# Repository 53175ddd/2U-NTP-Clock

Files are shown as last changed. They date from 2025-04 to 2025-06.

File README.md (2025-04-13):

# 自作 2U NTP 時計

KiCAD 8 にて開発しています．

## 取扱説明書

現在開発中のため，完成次第書きます．

## ファームウェアアップデート方法

> [!NOTE]
> 開発には Arduino 環境を使用しています．手順 0 に従って Arduino IDE をインストールしてください．

> [!NOTE]
> 既にインストール済みの場合は飛ばしてください．

### 手順 0 - 1｜Arduino IDE のインストールと初期設定

以下のリンクより，Arduino IDE のインストーラをダウンロードして，インストールします．

<https://arduino.cc/en/software/>

インストールしたら，[Ctrl] + [,] で基本設定を開き，`Luanguage:` の右のプルダウンメニューを展開して「日本語」を選択し，[OK] を押して日本語化します．  
その真下のチェックボックス 2 つにチェックを入れておくと良いでしょう．  
その後，以下の URL を「追加のボードマネージャの URL:」の欄にコピペします．

```
https://raw.githubusercontent.com/espressif/arduino-esp32/gh-pages/package_esp32_dev_index.json
```

### 手順 0 - 2｜ESP32 の開発環境のインストール

Arduino IDE のインストールができたら，ESP32 用の開発環境をインストールします．

[Ctrl] + [Shift] + [B] を押してボードマネージャを開き，検索窓に「ESP32」と入力します．  
すると「esp32 by Espressif Systems」がでてくるので，最新版をインストールします．

> [!WARNING]
> 結構時間がかかります．

### 手順 1 - 1｜GitHub リポジトリのクローン

Git コマンドあるいは GitHub Desktop などを用いて GitHub リポジトリをクローンするか，Zip でダウンロードし，任意のディレクトリに展開します．

### 手順 1 - 2｜Arduino スケッチの起動と修正

`./2U-NTP-Clock.ino` を開きます．

以下のような記述があるので，それをお使いの環境に合わせて変更します．

```cpp
/* Wi-Fi アクセスポイントの設定 */
/* "" の中身を変更してください． */

char ssid[] = "YOUR-SSID-HERE";
char psk[]  = "YOUR-PSK-HERE";
```

### 手順 1 - 3｜PC に接続

USB Type-C ケーブルで コントローラ（M5 Stamp-S3）と PC を接続します．

### 手順 1 - 4｜ビルドと書き込み

ボード選択画面から「M5StampS3」を選択し，COM ポートも選択します．

[Ctrl] + [U] でビルド & フラッシュします．

### 手順 2 - 1｜動作確認

ファームウェアを書き込むと自動的に再起動します．  
再起動後，正しく時刻同期ができるかを確認してください．

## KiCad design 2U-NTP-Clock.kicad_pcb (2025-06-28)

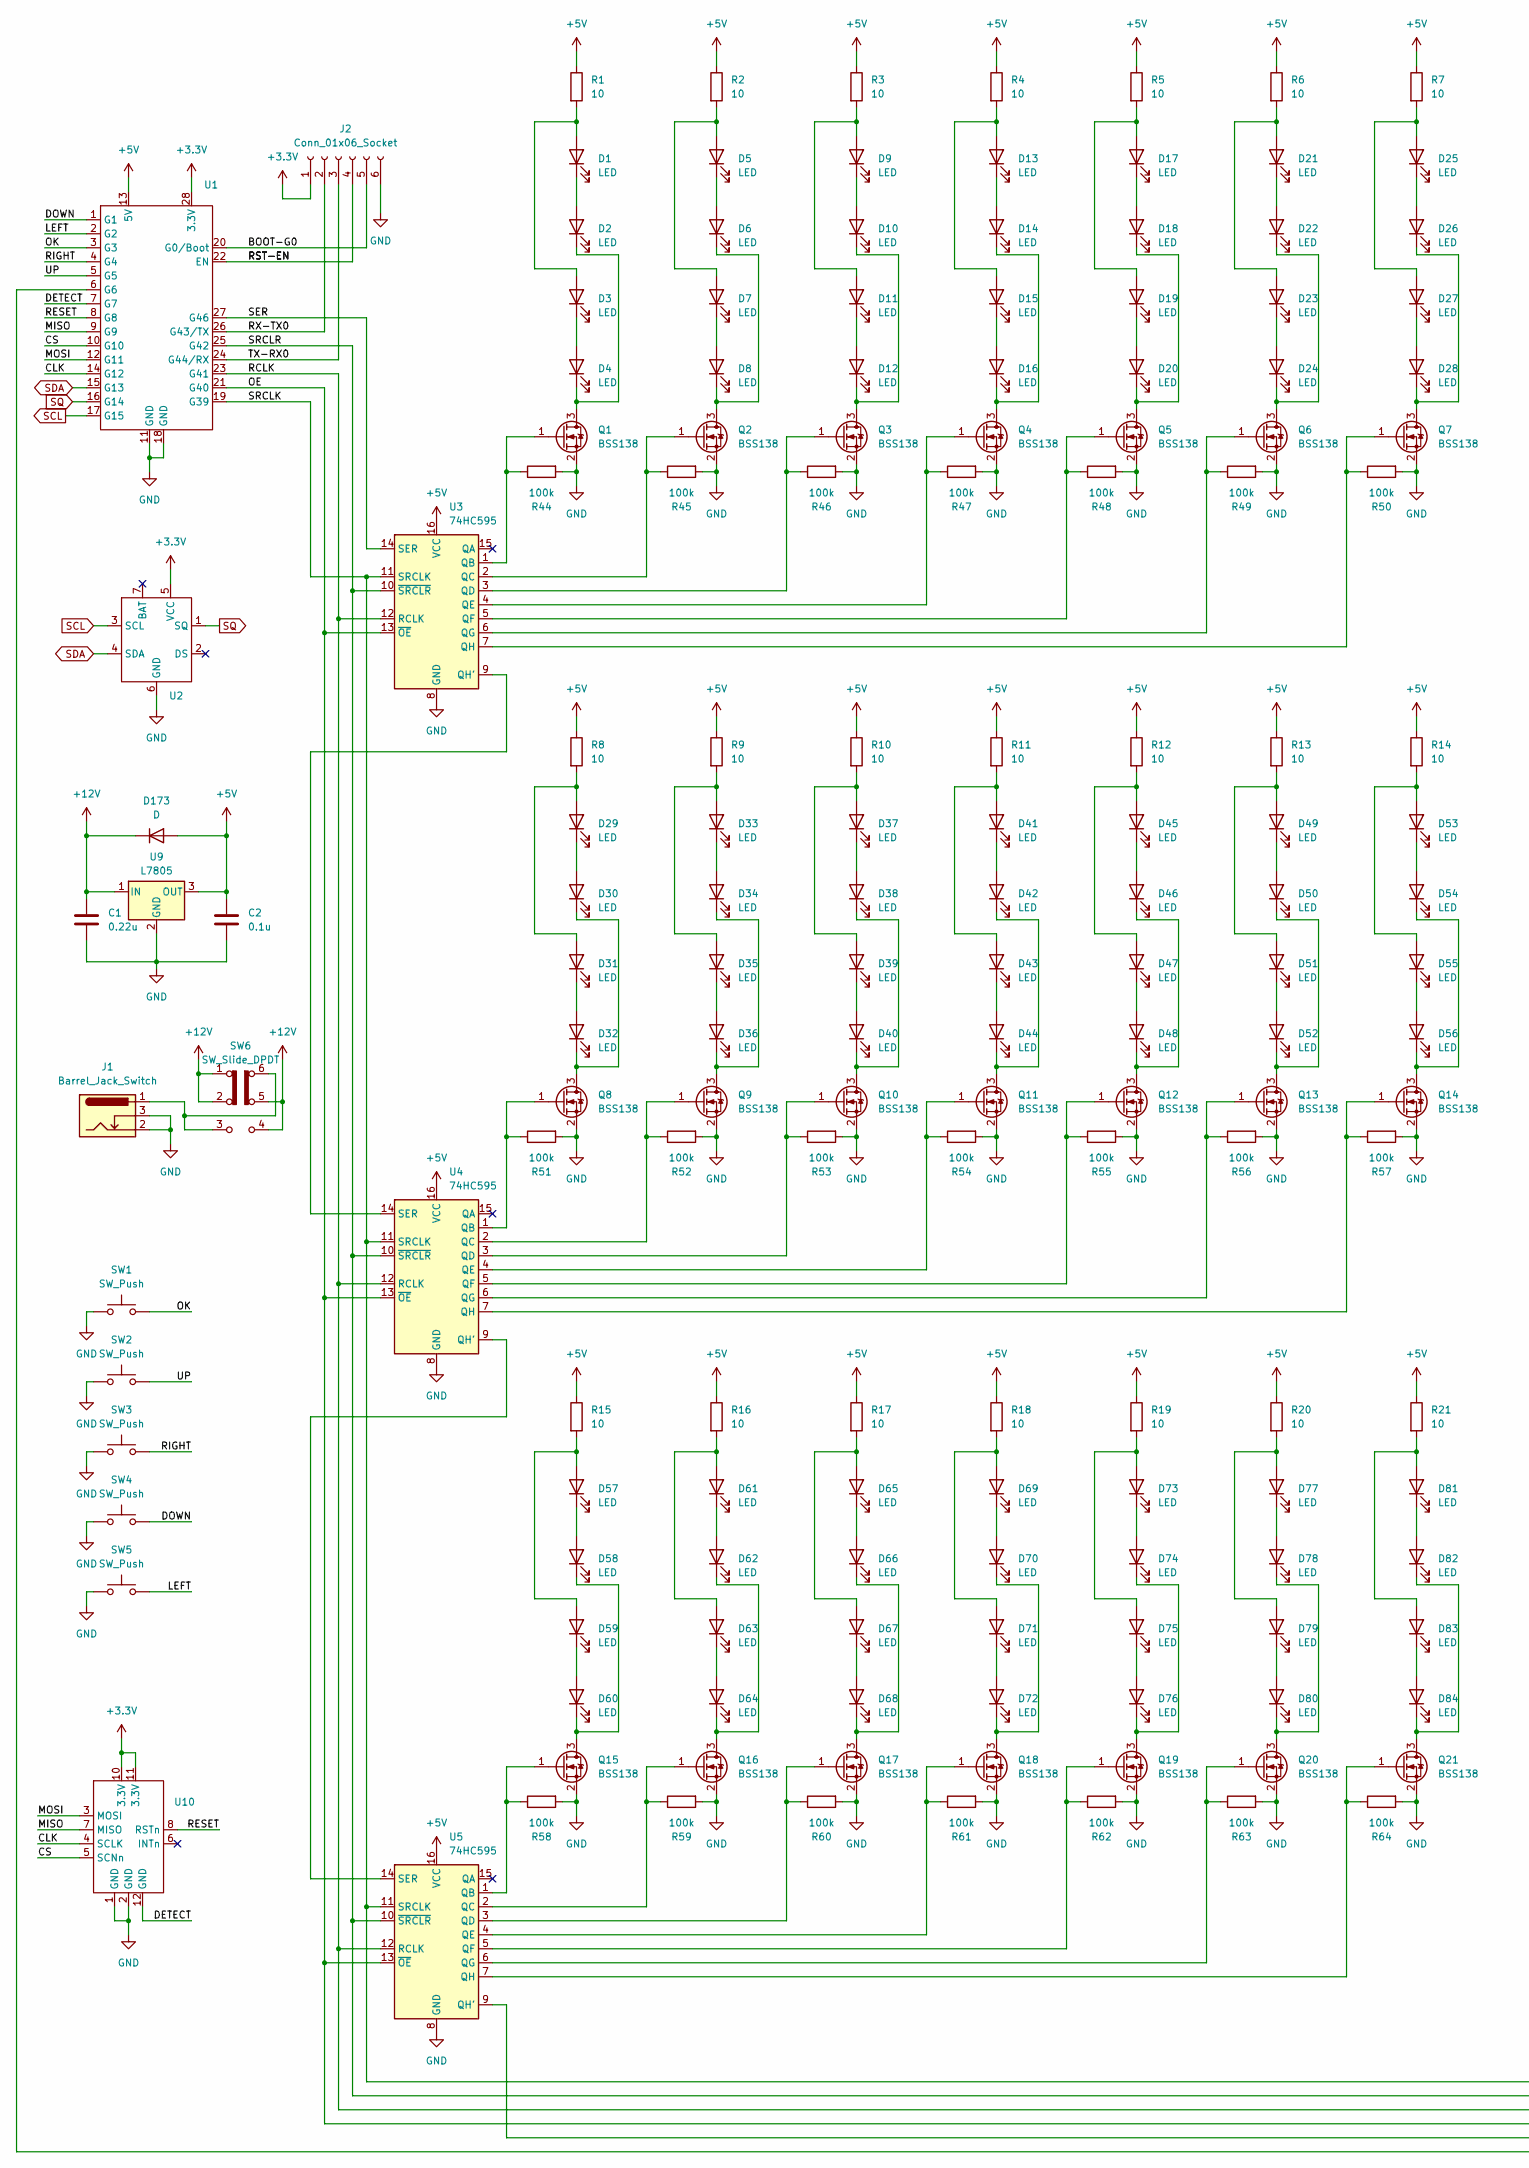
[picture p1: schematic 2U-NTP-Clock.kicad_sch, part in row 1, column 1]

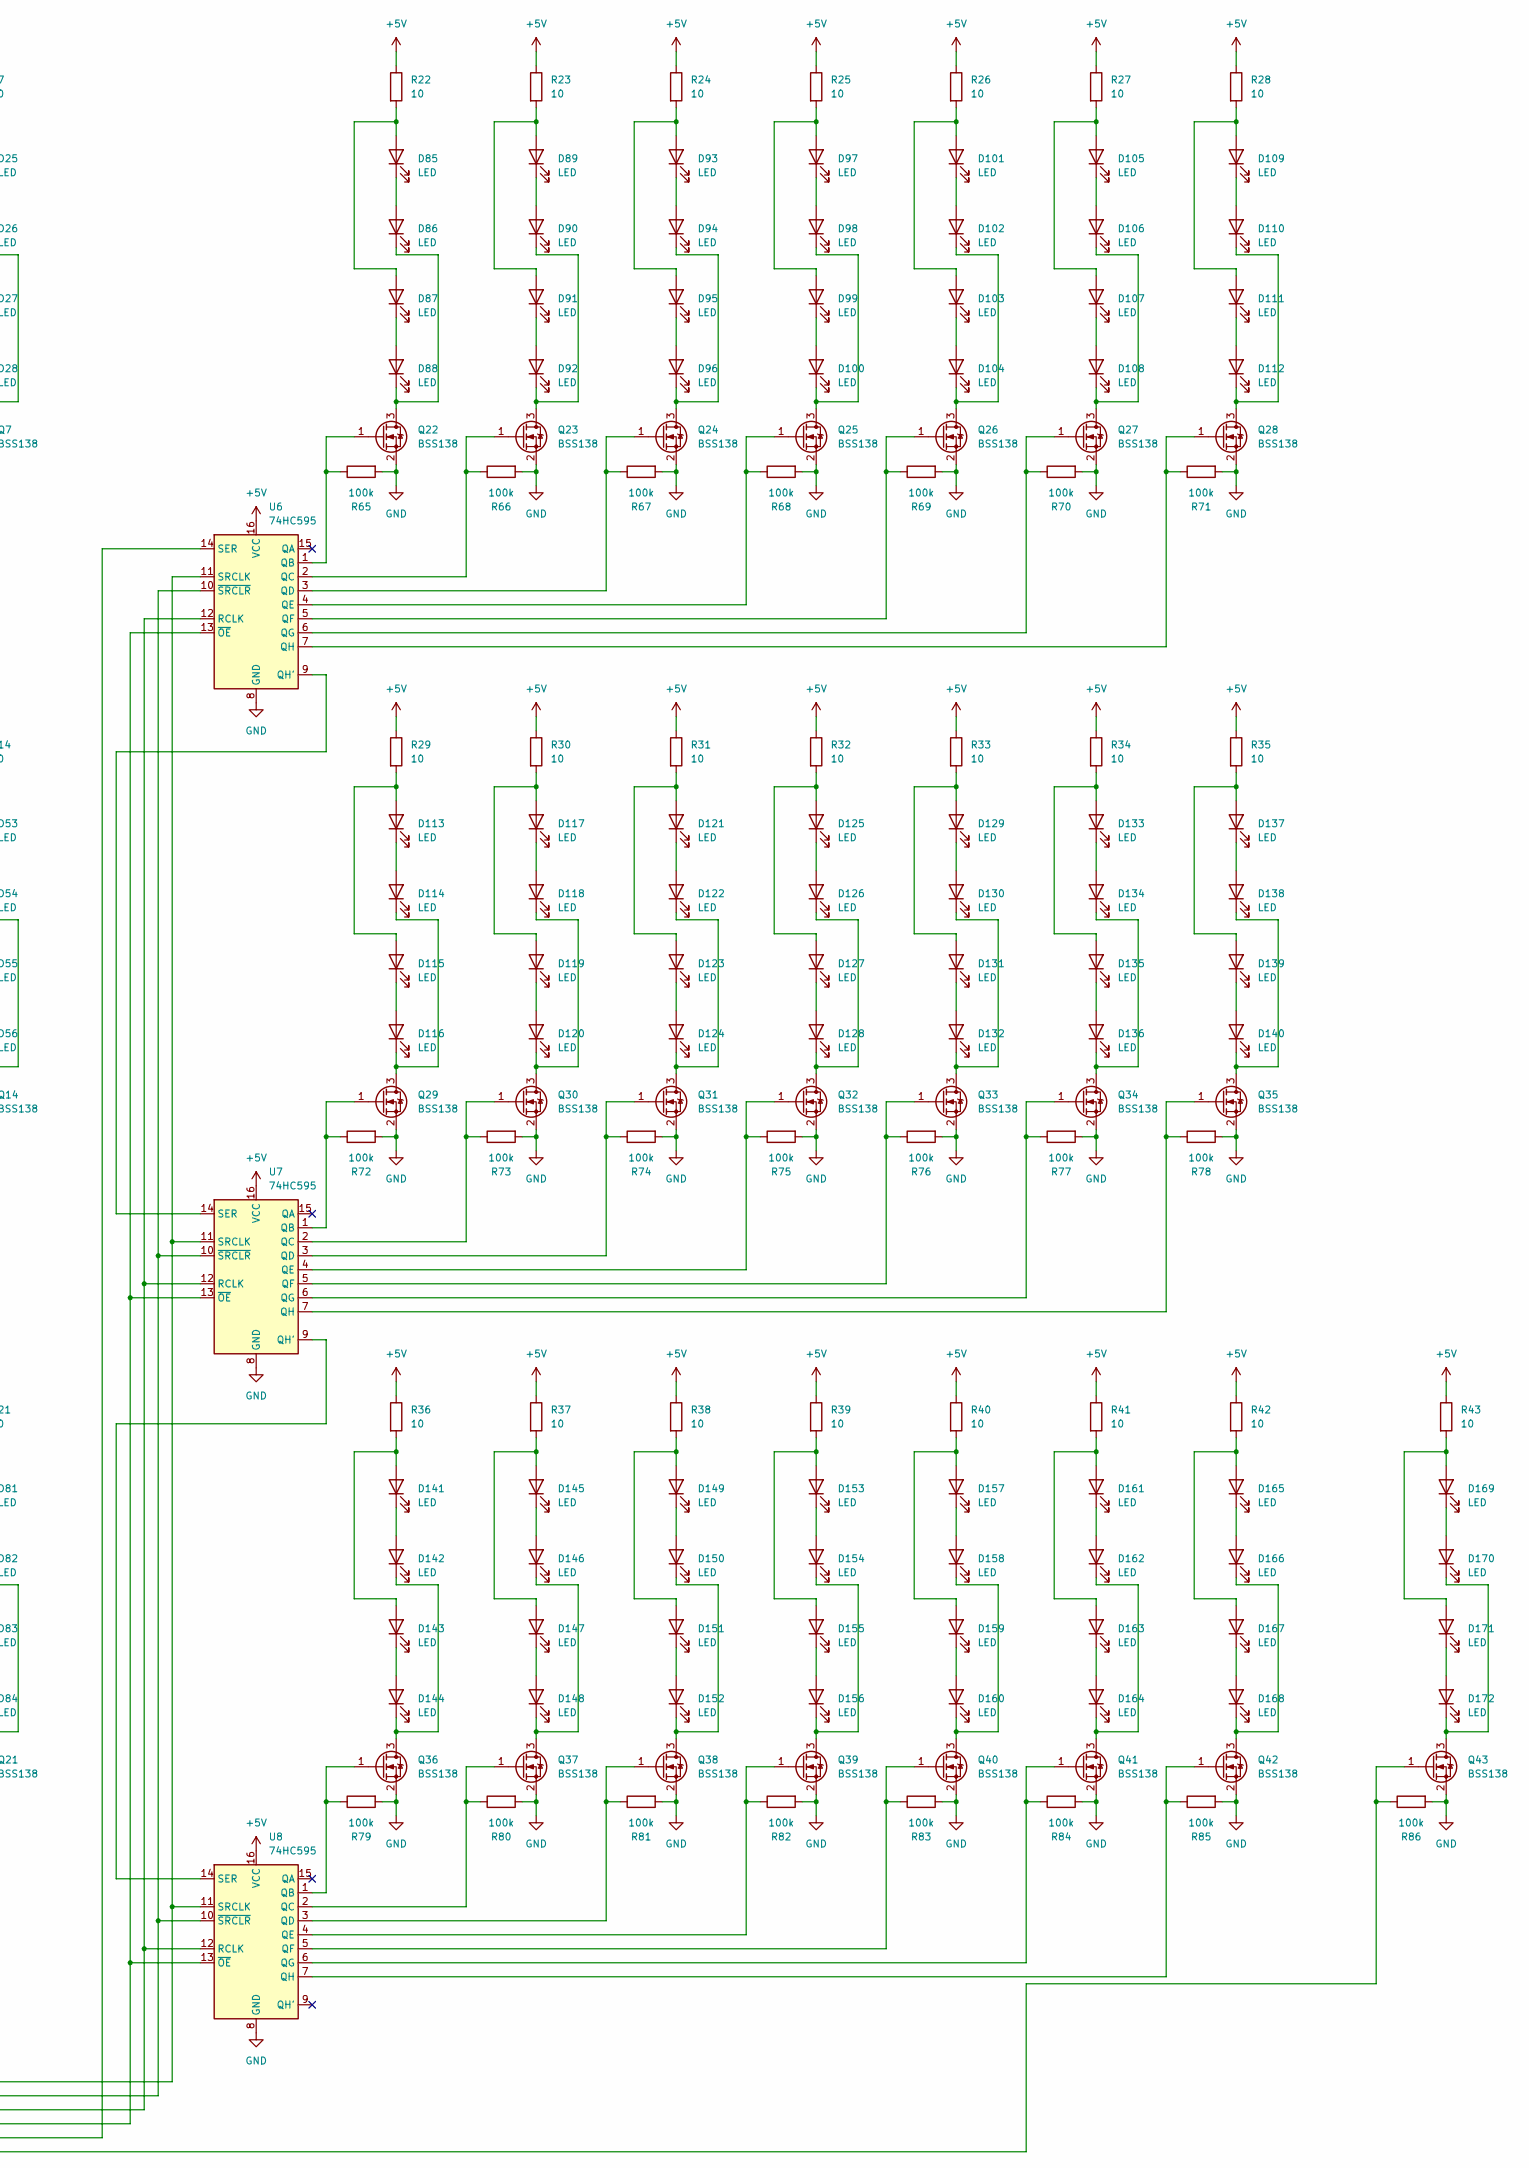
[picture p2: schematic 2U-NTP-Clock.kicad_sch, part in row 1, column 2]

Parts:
C1: 0.22u; C_0603_1608Metric; LCSC C14663
C2: 0.1u; C_0603_1608Metric; LCSC C14663
D1, D2, D3, D4, D5, D6, D7, D8, D9, D10, D11, D12, D13, D14, D15, D16, D17, D18, D19, D20, D21, D22, D23, D24, D25, D26, D27, D28, D29, D30, D31, D32, D33, D34, D35, D36, D37, D38, D39, D40, D41, D42, D43, D44, D45, D46, D47, D48, D49, D50, D51, D52, D53, D54, D55, D56, D57, D58, D59, D60, D61, D62, D63, D64, D65, D66, D67, D68, D69, D70, D71, D72, D73, D74, D75, D76, D77, D78, D79, D80, D81, D82, D83, D84, D85, D86, D87, D88, D89, D90, D91, D92, D93, D94, D95, D96, D97, D98, D99, D100, D101, D102, D103, D104, D105, D106, D107, D108, D109, D110, D111, D112, D113, D114, D115, D116, D117, D118, D119, D120, D121, D122, D123, D124, D125, D126, D127, D128, D129, D130, D131, D132, D133, D134, D135, D136, D137, D138, D139, D140, D141, D142, D143, D144, D145, D146, D147, D148, D149, D150, D151, D152, D153, D154, D155, D156, D157, D158, D159, D160, D161, D162, D163, D164, D165, D166, D167, D168, D169, D170, D171, D172: LED; LED_D5.0mm; LCSC C2895492
D173: D; D_SOD-523; LCSC C232841
J1: Barrel_Jack_Switch; BarrelJack_Horizontal
J2: Conn_01x06_Socket; PinSocket_1x06_P2.54mm_Vertical
Q1, Q2, Q3, Q4, Q5, Q6, Q7, Q8, Q9, Q10, Q11, Q12, Q13, Q14, Q15, Q16, Q17, Q18, Q19, Q20, Q21, Q22, Q23, Q24, Q25, Q26, Q27, Q28, Q29, Q30, Q31, Q32, Q33, Q34, Q35, Q36, Q37, Q38, Q39, Q40, Q41, Q42, Q43: BSS138; SOT-23; LCSC C82045
R1, R2, R3, R4, R5, R6, R7, R8, R9, R10, R11, R12, R13, R14, R15, R16, R17, R18, R19, R20, R21, R22, R23, R24, R25, R26, R27, R28, R29, R30, R31, R32, R33, R34, R35, R36, R37, R38, R39, R40, R41, R42, R43: 10; R_0603_1608Metric; LCSC C109318
R44, R45, R46, R47, R48, R49, R50, R51, R52, R53, R54, R55, R56, R57, R58, R59, R60, R61, R62, R63, R64, R65, R66, R67, R68, R69, R70, R71, R72, R73, R74, R75, R76, R77, R78, R79, R80, R81, R82, R83, R84, R85, R86: 100k; R_0603_1608Metric; LCSC C14675
SW1, SW2, SW3, SW4, SW5: SW_Push; SW_PUSH_6mm
SW6: SW_Slide_DPDT; SW_E-Switch_EG1271_SPDT
U1: STAMP-S3-DIP
U2: TinyRTC_Battery_Side_Up
U3, U4, U5, U6, U7, U8: 74HC595; SOIC-16_3.9x9.9mm_P1.27mm; LCSC C5947
U9: L7805; TO-252-2; LCSC C22376607
U10: WIZ850io

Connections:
+3.3V: J2.1, U1.28 (3.3V), U2.5 (VCC), U10.10 (3.3V), U10.11 (3.3V)
+5V: C2.1, D173.2 (A), R1.1, R2.1, R3.1, R4.1, R5.1, R6.1, R7.1, R8.1, R9.1, R10.1, R11.1, R12.1, R13.1, R14.1, R15.1, R16.1, R17.1, R18.1, R19.1, R20.1, R21.1, R22.1, R23.1, R24.1, R25.1, R26.1, R27.1, R28.1, R29.1, R30.1, R31.1, R32.1, R33.1, R34.1, R35.1, R36.1, R37.1, R38.1, R39.1, R40.1, R41.1, R42.1, R43.1, U1.13 (5V), U3.16 (VCC), U4.16 (VCC), U5.16 (VCC), U6.16 (VCC), U7.16 (VCC), U8.16 (VCC), U9.3 (OUT)
+12V: C1.1, D173.1 (K), SW6.1 (A), SW6.2 (B), SW6.4 (A), SW6.5 (B), U9.1 (IN)
/BOOT-G0: J2.5, U1.20 (G0/Boot)
/CLK: U1.14 (G12), U10.4 (SCLK)
/CS: U1.10 (G10), U10.5 (SCNn)
/DETECT: U1.7 (G7), U10.12 (GND)
/DOWN: SW4.1, U1.1 (G1)
/LEFT: SW5.1, U1.2 (G2)
/MISO: U1.9 (G9), U10.7 (MISO)
/MOSI: U1.12 (G11), U10.3 (MOSI)
/OE: U1.21 (G40), U3.13 (~OE), U4.13 (~OE), U5.13 (~OE), U6.13 (~OE), U7.13 (~OE), U8.13 (~OE)
/OK: SW1.1, U1.3 (G3)
/RCLK: U1.23 (G41), U3.12 (RCLK), U4.12 (RCLK), U5.12 (RCLK), U6.12 (RCLK), U7.12 (RCLK), U8.12 (RCLK)
/RESET: U1.8 (G8), U10.8 (RSTn)
/RIGHT: SW3.1, U1.4 (G4)
/RX-TX0: J2.2, U1.26 (G43/TX)
/SER: U1.27 (G46), U3.14 (SER)
/SRCLK: U1.19 (G39), U3.11 (SRCLK), U4.11 (SRCLK), U5.11 (SRCLK), U6.11 (SRCLK), U7.11 (SRCLK), U8.11 (SRCLK)
/SRCLR: U1.25 (G42), U3.10 (~SRCLR), U4.10 (~SRCLR), U5.10 (~SRCLR), U6.10 (~SRCLR), U7.10 (~SRCLR), U8.10 (~SRCLR)
/TX-RX0: J2.3, U1.24 (G44/RX)
/UP: SW2.1, U1.5 (G5)
GND: C1.2, C2.2, J1.2, J1.3, J2.6, Q1.2 (S), Q2.2 (S), Q3.2 (S), Q4.2 (S), Q5.2 (S), Q6.2 (S), Q7.2 (S), Q8.2 (S), Q9.2 (S), Q10.2 (S), Q11.2 (S), Q12.2 (S), Q13.2 (S), Q14.2 (S), Q15.2 (S), Q16.2 (S), Q17.2 (S), Q18.2 (S), Q19.2 (S), Q20.2 (S), Q21.2 (S), Q22.2 (S), Q23.2 (S), Q24.2 (S), Q25.2 (S), Q26.2 (S), Q27.2 (S), Q28.2 (S), Q29.2 (S), Q30.2 (S), Q31.2 (S), Q32.2 (S), Q33.2 (S), Q34.2 (S), Q35.2 (S), Q36.2 (S), Q37.2 (S), Q38.2 (S), Q39.2 (S), Q40.2 (S), Q41.2 (S), Q42.2 (S), Q43.2 (S), R44.2, R45.2, R46.2, R47.2, R48.2, R49.2, R50.2, R51.2, R52.2, R53.2, R54.2, R55.2, R56.2, R57.2, R58.2, R59.2, R60.2, R61.2, R62.2, R63.2, R64.2, R65.2, R66.2, R67.2, R68.2, R69.2, R70.2, R71.2, R72.2, R73.2, R74.2, R75.2, R76.2, R77.2, R78.2, R79.2, R80.2, R81.2, R82.2, R83.2, R84.2, R85.2, R86.2, SW1.2, SW2.2, SW3.2, SW4.2, SW5.2, U1.11 (GND), U1.18 (GND), U2.6 (GND), U3.8 (GND), U4.8 (GND), U5.8 (GND), U6.8 (GND), U7.8 (GND), U8.8 (GND), U9.2 (GND), U10.1 (GND), U10.2 (GND)
unnamed: D1.2 (A), D3.2 (A), R1.2
unnamed: D1.1 (K), D2.2 (A)
unnamed: D2.1 (K), D4.1 (K), Q1.3 (D)
unnamed: D3.1 (K), D4.2 (A)
unnamed: D5.2 (A), D7.2 (A), R2.2
unnamed: D5.1 (K), D6.2 (A)
unnamed: D6.1 (K), D8.1 (K), Q2.3 (D)
unnamed: D7.1 (K), D8.2 (A)
unnamed: D9.1 (K), D10.2 (A)
unnamed: D10.1 (K), D12.1 (K), Q3.3 (D)
unnamed: D9.2 (A), D11.2 (A), R3.2
unnamed: D11.1 (K), D12.2 (A)
unnamed: D13.2 (A), D15.2 (A), R4.2
unnamed: D13.1 (K), D14.2 (A)
unnamed: D14.1 (K), D16.1 (K), Q4.3 (D)
unnamed: D15.1 (K), D16.2 (A)
unnamed: D17.2 (A), D19.2 (A), R5.2
unnamed: D17.1 (K), D18.2 (A)
unnamed: D18.1 (K), D20.1 (K), Q5.3 (D)
unnamed: D19.1 (K), D20.2 (A)
unnamed: D21.2 (A), D23.2 (A), R6.2
unnamed: D21.1 (K), D22.2 (A)
unnamed: D22.1 (K), D24.1 (K), Q6.3 (D)
unnamed: D23.1 (K), D24.2 (A)
unnamed: D25.2 (A), D27.2 (A), R7.2
unnamed: D25.1 (K), D26.2 (A)
unnamed: D26.1 (K), D28.1 (K), Q7.3 (D)
unnamed: D27.1 (K), D28.2 (A)
unnamed: D29.2 (A), D31.2 (A), R8.2
unnamed: D29.1 (K), D30.2 (A)
unnamed: D30.1 (K), D32.1 (K), Q8.3 (D)
unnamed: D31.1 (K), D32.2 (A)
unnamed: D33.2 (A), D35.2 (A), R9.2
unnamed: D33.1 (K), D34.2 (A)
unnamed: D34.1 (K), D36.1 (K), Q9.3 (D)
unnamed: D35.1 (K), D36.2 (A)
unnamed: D37.2 (A), D39.2 (A), R10.2
unnamed: D37.1 (K), D38.2 (A)
unnamed: D38.1 (K), D40.1 (K), Q10.3 (D)
unnamed: D39.1 (K), D40.2 (A)
unnamed: D41.2 (A), D43.2 (A), R11.2
unnamed: D41.1 (K), D42.2 (A)
unnamed: D42.1 (K), D44.1 (K), Q11.3 (D)
unnamed: D43.1 (K), D44.2 (A)
unnamed: D45.2 (A), D47.2 (A), R12.2
unnamed: D45.1 (K), D46.2 (A)
unnamed: D46.1 (K), D48.1 (K), Q12.3 (D)
unnamed: D47.1 (K), D48.2 (A)
unnamed: D49.2 (A), D51.2 (A), R13.2
unnamed: D49.1 (K), D50.2 (A)
unnamed: D50.1 (K), D52.1 (K), Q13.3 (D)
unnamed: D51.1 (K), D52.2 (A)
unnamed: D53.2 (A), D55.2 (A), R14.2
unnamed: D53.1 (K), D54.2 (A)
unnamed: D54.1 (K), D56.1 (K), Q14.3 (D)
unnamed: D55.1 (K), D56.2 (A)
unnamed: D57.2 (A), D59.2 (A), R15.2
unnamed: D57.1 (K), D58.2 (A)
unnamed: D58.1 (K), D60.1 (K), Q15.3 (D)
unnamed: D59.1 (K), D60.2 (A)
unnamed: D61.2 (A), D63.2 (A), R16.2
unnamed: D61.1 (K), D62.2 (A)
unnamed: D62.1 (K), D64.1 (K), Q16.3 (D)
unnamed: D63.1 (K), D64.2 (A)
unnamed: D65.2 (A), D67.2 (A), R17.2
unnamed: D65.1 (K), D66.2 (A)
unnamed: D66.1 (K), D68.1 (K), Q17.3 (D)
unnamed: D67.1 (K), D68.2 (A)
unnamed: D69.2 (A), D71.2 (A), R18.2
unnamed: D69.1 (K), D70.2 (A)
unnamed: D70.1 (K), D72.1 (K), Q18.3 (D)
unnamed: D71.1 (K), D72.2 (A)
unnamed: D73.2 (A), D75.2 (A), R19.2
unnamed: D73.1 (K), D74.2 (A)
unnamed: D74.1 (K), D76.1 (K), Q19.3 (D)
unnamed: D75.1 (K), D76.2 (A)
unnamed: D77.2 (A), D79.2 (A), R20.2
unnamed: D77.1 (K), D78.2 (A)
unnamed: D78.1 (K), D80.1 (K), Q20.3 (D)
unnamed: D79.1 (K), D80.2 (A)
unnamed: D81.2 (A), D83.2 (A), R21.2
unnamed: D81.1 (K), D82.2 (A)
unnamed: D82.1 (K), D84.1 (K), Q21.3 (D)
unnamed: D83.1 (K), D84.2 (A)
unnamed: D85.2 (A), D87.2 (A), R22.2
unnamed: D85.1 (K), D86.2 (A)
unnamed: D86.1 (K), D88.1 (K), Q22.3 (D)
unnamed: D87.1 (K), D88.2 (A)
unnamed: D89.2 (A), D91.2 (A), R23.2
unnamed: D89.1 (K), D90.2 (A)
unnamed: D90.1 (K), D92.1 (K), Q23.3 (D)
unnamed: D91.1 (K), D92.2 (A)
unnamed: D93.2 (A), D95.2 (A), R24.2
unnamed: D93.1 (K), D94.2 (A)
unnamed: D94.1 (K), D96.1 (K), Q24.3 (D)
unnamed: D95.1 (K), D96.2 (A)
unnamed: D97.2 (A), D99.2 (A), R25.2
unnamed: D97.1 (K), D98.2 (A)
unnamed: D99.1 (K), D100.2 (A)
unnamed: D98.1 (K), D100.1 (K), Q25.3 (D)
unnamed: D101.2 (A), D103.2 (A), R26.2
unnamed: D101.1 (K), D102.2 (A)
unnamed: D102.1 (K), D104.1 (K), Q26.3 (D)
unnamed: D103.1 (K), D104.2 (A)
unnamed: D105.2 (A), D107.2 (A), R27.2
unnamed: D105.1 (K), D106.2 (A)
unnamed: D106.1 (K), D108.1 (K), Q27.3 (D)
unnamed: D107.1 (K), D108.2 (A)
unnamed: D109.2 (A), D111.2 (A), R28.2
unnamed: D109.1 (K), D110.2 (A)
unnamed: D110.1 (K), D112.1 (K), Q28.3 (D)
unnamed: D111.1 (K), D112.2 (A)
unnamed: D113.2 (A), D115.2 (A), R29.2
unnamed: D113.1 (K), D114.2 (A)
unnamed: D114.1 (K), D116.1 (K), Q29.3 (D)
unnamed: D115.1 (K), D116.2 (A)
unnamed: D117.2 (A), D119.2 (A), R30.2
unnamed: D117.1 (K), D118.2 (A)
unnamed: D118.1 (K), D120.1 (K), Q30.3 (D)
unnamed: D119.1 (K), D120.2 (A)
unnamed: D121.2 (A), D123.2 (A), R31.2
unnamed: D121.1 (K), D122.2 (A)
unnamed: D122.1 (K), D124.1 (K), Q31.3 (D)
unnamed: D123.1 (K), D124.2 (A)
unnamed: D125.2 (A), D127.2 (A), R32.2
unnamed: D125.1 (K), D126.2 (A)
unnamed: D126.1 (K), D128.1 (K), Q32.3 (D)
unnamed: D127.1 (K), D128.2 (A)
unnamed: D129.2 (A), D131.2 (A), R33.2
unnamed: D129.1 (K), D130.2 (A)
unnamed: D130.1 (K), D132.1 (K), Q33.3 (D)
unnamed: D131.1 (K), D132.2 (A)
unnamed: D133.2 (A), D135.2 (A), R34.2
unnamed: D133.1 (K), D134.2 (A)
unnamed: D134.1 (K), D136.1 (K), Q34.3 (D)
unnamed: D135.1 (K), D136.2 (A)
unnamed: D137.2 (A), D139.2 (A), R35.2
unnamed: D137.1 (K), D138.2 (A)
unnamed: D138.1 (K), D140.1 (K), Q35.3 (D)
unnamed: D139.1 (K), D140.2 (A)
unnamed: D141.2 (A), D143.2 (A), R36.2
unnamed: D141.1 (K), D142.2 (A)
unnamed: D142.1 (K), D144.1 (K), Q36.3 (D)
unnamed: D143.1 (K), D144.2 (A)
unnamed: D145.2 (A), D147.2 (A), R37.2
unnamed: D145.1 (K), D146.2 (A)
unnamed: D146.1 (K), D148.1 (K), Q37.3 (D)
unnamed: D147.1 (K), D148.2 (A)
unnamed: D149.2 (A), D151.2 (A), R38.2
unnamed: D149.1 (K), D150.2 (A)
unnamed: D150.1 (K), D152.1 (K), Q38.3 (D)
unnamed: D151.1 (K), D152.2 (A)
unnamed: D153.2 (A), D155.2 (A), R39.2
unnamed: D153.1 (K), D154.2 (A)
unnamed: D154.1 (K), D156.1 (K), Q39.3 (D)
unnamed: D155.1 (K), D156.2 (A)
unnamed: D157.2 (A), D159.2 (A), R40.2
unnamed: D157.1 (K), D158.2 (A)
unnamed: D158.1 (K), D160.1 (K), Q40.3 (D)
unnamed: D159.1 (K), D160.2 (A)
unnamed: D161.2 (A), D163.2 (A), R41.2
unnamed: D161.1 (K), D162.2 (A)
unnamed: D162.1 (K), D164.1 (K), Q41.3 (D)
unnamed: D163.1 (K), D164.2 (A)
unnamed: D165.2 (A), D167.2 (A), R42.2
unnamed: D165.1 (K), D166.2 (A)
unnamed: D166.1 (K), D168.1 (K), Q42.3 (D)
unnamed: D167.1 (K), D168.2 (A)
unnamed: D169.2 (A), D171.2 (A), R43.2
unnamed: D169.1 (K), D170.2 (A)
unnamed: D170.1 (K), D172.1 (K), Q43.3 (D)
unnamed: D171.1 (K), D172.2 (A)
unnamed: J1.1, SW6.3 (C), SW6.6 (C)
unnamed: J2.4, U1.22 (EN)
unnamed: Q1.1 (G), R44.1, U3.1 (QB)
unnamed: Q2.1 (G), R45.1, U3.2 (QC)
unnamed: Q3.1 (G), R46.1, U3.3 (QD)
unnamed: Q4.1 (G), R47.1, U3.4 (QE)
unnamed: Q5.1 (G), R48.1, U3.5 (QF)
unnamed: Q6.1 (G), R49.1, U3.6 (QG)
unnamed: Q7.1 (G), R50.1, U3.7 (QH)
unnamed: Q8.1 (G), R51.1, U4.1 (QB)
unnamed: Q9.1 (G), R52.1, U4.2 (QC)
unnamed: Q10.1 (G), R53.1, U4.3 (QD)
unnamed: Q11.1 (G), R54.1, U4.4 (QE)
unnamed: Q12.1 (G), R55.1, U4.5 (QF)
unnamed: Q13.1 (G), R56.1, U4.6 (QG)
unnamed: Q14.1 (G), R57.1, U4.7 (QH)
unnamed: Q15.1 (G), R58.1, U5.1 (QB)
unnamed: Q16.1 (G), R59.1, U5.2 (QC)
unnamed: Q17.1 (G), R60.1, U5.3 (QD)
unnamed: Q18.1 (G), R61.1, U5.4 (QE)
unnamed: Q19.1 (G), R62.1, U5.5 (QF)
unnamed: Q20.1 (G), R63.1, U5.6 (QG)
unnamed: Q21.1 (G), R64.1, U5.7 (QH)
unnamed: Q22.1 (G), R65.1, U6.1 (QB)
unnamed: Q23.1 (G), R66.1, U6.2 (QC)
unnamed: Q24.1 (G), R67.1, U6.3 (QD)
unnamed: Q25.1 (G), R68.1, U6.4 (QE)
unnamed: Q26.1 (G), R69.1, U6.5 (QF)
unnamed: Q27.1 (G), R70.1, U6.6 (QG)
unnamed: Q28.1 (G), R71.1, U6.7 (QH)
unnamed: Q29.1 (G), R72.1, U7.1 (QB)
unnamed: Q30.1 (G), R73.1, U7.2 (QC)
unnamed: Q31.1 (G), R74.1, U7.3 (QD)
unnamed: Q32.1 (G), R75.1, U7.4 (QE)
unnamed: Q33.1 (G), R76.1, U7.5 (QF)
unnamed: Q34.1 (G), R77.1, U7.6 (QG)
unnamed: Q35.1 (G), R78.1, U7.7 (QH)
unnamed: Q36.1 (G), R79.1, U8.1 (QB)
unnamed: Q37.1 (G), R80.1, U8.2 (QC)
unnamed: Q38.1 (G), R81.1, U8.3 (QD)
unnamed: Q39.1 (G), R82.1, U8.4 (QE)
unnamed: Q40.1 (G), R83.1, U8.5 (QF)
unnamed: Q41.1 (G), R84.1, U8.6 (QG)
unnamed: Q42.1 (G), R85.1, U8.7 (QH)
unnamed: Q43.1 (G), R86.1, U1.6 (G6)
unnamed: U3.9 (QH'), U4.14 (SER)
unnamed: U4.9 (QH'), U5.14 (SER)
unnamed: U5.9 (QH'), U6.14 (SER)
unnamed: U6.9 (QH'), U7.14 (SER)
unnamed: U7.9 (QH'), U8.14 (SER)
SCL: U1.17 (G15), U2.3 (SCL)
SDA: U1.15 (G13), U2.4 (SDA)
SQ: U1.16 (G14), U2.1 (SQ)

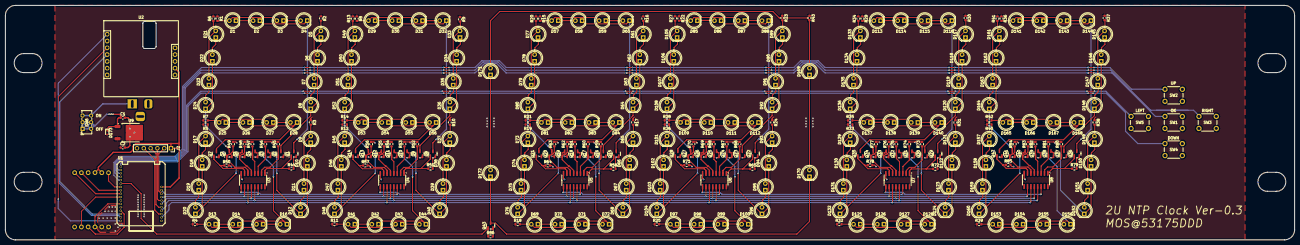
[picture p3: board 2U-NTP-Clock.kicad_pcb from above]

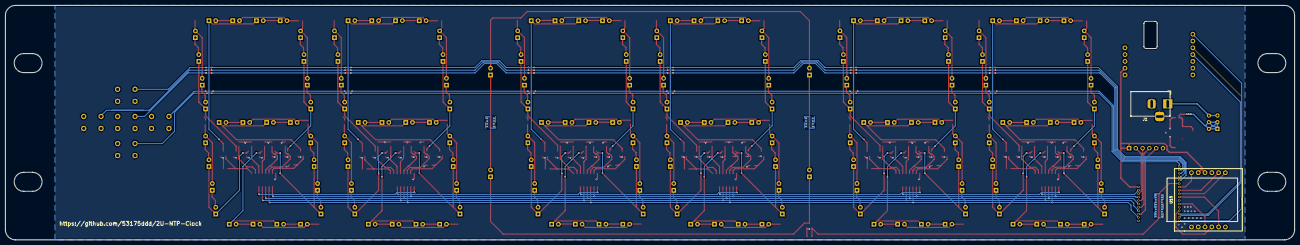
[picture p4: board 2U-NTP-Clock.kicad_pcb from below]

Board: 2 copper layers, 482.6 x 87.8 mm, 322 parts (2 on the bottom side), 248 nets.

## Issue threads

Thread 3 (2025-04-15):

初回起動時に AP として起動させて初期設定できないか検証

53175ddd, 2025-04-15:

53175ddd, 2025-04-15:
Stamp-S3 単体でテストする

53175ddd, 2025-04-16:
ESP32 を AP として開始する最小限のコード

```cpp
#include <WiFi.h>

/* Wi-Fi アクセスポイントの設定 */
#define MY_SSID "2U-NTP-Clock-setup"
#define MY_PSK  "esp32setup"

#define BAUDRATE 115200

IPAddress local(192, 168, 1, 254);
IPAddress gateway(192, 168, 1, 254);
IPAddress subnet(255, 255, 255, 0);

void setup() {
  Serial.begin(BAUDRATE);
  wifi_setup();
}

void loop() {
}

void wifi_setup(void) {
  WiFi.mode(WIFI_MODE_AP);

  if(WiFi.softAP(MY_SSID, MY_PSK)) {
    Serial.print("Success to start AP.\n");
  }else {
    Serial.print("Failed to start AP...\n");

    return;
  }

  if(WiFi.softAPConfig(local, gateway, subnet)) {
    Serial.print("Success to configure.\n");
  }else {
    Serial.print("Failed to configure...\n");

    return;
  }

  Serial.print("Wi-Fi Setup done!\n");
  Serial.printf("IP Address of this Access Point : %s\n", WiFi.softAPIP().toString().c_str());

  return;
}
```

53175ddd, 2025-05-02:
NVS 使うことで実現できたので CLOSE

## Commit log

2025-04-11 PJ 作成
    [2U-NTP-Clock.kicad_pcb, 2U-NTP-Clock.kicad_sch]
2025-04-11 基板外形作成
    [2U-NTP-Clock.kicad_pcb]
2025-04-11 RTC のシンボルとフットプリント追加
2025-04-11 シンボル・フットプリント読み込み
2025-04-11 StampS3 追加
2025-04-11 回路図作成
    [2U-NTP-Clock.kicad_pcb]
2025-04-11 回路図書いた
    [2U-NTP-Clock.kicad_sch]
2025-04-12 トランジスタ以外配置した
    [2U-NTP-Clock.kicad_pcb]
2025-04-12 配線した
    [2U-NTP-Clock.kicad_pcb]
2025-04-12 仕上げた
    [2U-NTP-Clock.kicad_pcb, 2U-NTP-Clock.kicad_sch]
2025-04-12 製造データ吐き出し
    [2U-NTP-Clock.kicad_pcb]
2025-04-12 スイッチの追加と配置配線修正
    [2U-NTP-Clock.kicad_pcb, 2U-NTP-Clock.kicad_sch]
2025-04-12 わすれてた GND を繋いで製造データ出力
    [2U-NTP-Clock.kicad_pcb, 2U-NTP-Clock.kicad_sch]
2025-04-12 README をざっくり書いた
2025-04-12 ベタ塗りの範囲を広げた
    [2U-NTP-Clock.kicad_pcb]
2025-04-13 コードに合わせて変更
2025-04-14 Eth モジュールのシンボル作成
    [2U-NTP-Clock.kicad_sch]
2025-04-14 デバッグポート・Eth PHY の実装
    [2U-NTP-Clock.kicad_sch]
2025-04-14 Eth PHY モジュールのフットプリント作った
2025-04-14 追加部品にフットプリント割り当て
    [2U-NTP-Clock.kicad_sch]
2025-04-14 Ethernet とデバッグポート乗せた
    [2U-NTP-Clock.kicad_pcb]
2025-04-14 邪魔なシルクを削除
    [2U-NTP-Clock.kicad_pcb]
2025-04-14 GND つながってなかった
    [2U-NTP-Clock.kicad_pcb]
2025-04-14 via の径を変更
    [2U-NTP-Clock.kicad_pcb]
2025-04-14 部品の割り当てを変更
    [2U-NTP-Clock.kicad_pcb, 2U-NTP-Clock.kicad_sch]
2025-04-18 操作用スイッチを移設
    [2U-NTP-Clock.kicad_pcb]
2025-05-02 配線修正
    [2U-NTP-Clock.kicad_sch]
2025-05-02 基板配線修正
    [2U-NTP-Clock.kicad_pcb]
2025-05-02 スイッチ位置変更
    [2U-NTP-Clock.kicad_pcb]
2025-05-02 基板概形修正
    [2U-NTP-Clock.kicad_pcb]
2025-05-02 シルクのバージョンアップ
    [2U-NTP-Clock.kicad_pcb]
2025-05-02 コンフリクト修正
    [2U-NTP-Clock.kicad_pcb]
2025-05-04 アップデート
    ランドの径の変更
    配線取り回しの変更
    など
    [2U-NTP-Clock.kicad_pcb]
2025-05-04 ベタの取り回しをいい感じにした
    [2U-NTP-Clock.kicad_pcb]
2025-05-13 ベタ修正
    [2U-NTP-Clock.kicad_pcb]
2025-06-21 また回路間違えてたので修正
    [2U-NTP-Clock.kicad_sch]
2025-06-21 手動修正
    [2U-NTP-Clock.kicad_sch]
2025-06-21 破綻箇所修正
    [2U-NTP-Clock.kicad_sch]
2025-06-21 AW 修正
    [2U-NTP-Clock.kicad_pcb]
2025-06-21 穴寸法調整
    [2U-NTP-Clock.kicad_pcb]
2025-06-21 バージョンアップ
    [2U-NTP-Clock.kicad_pcb]
2025-06-28 MOSFET のプルダウン抵抗を追加
    [2U-NTP-Clock.kicad_sch]
2025-06-28 PD抵抗配置配線
    [2U-NTP-Clock.kicad_pcb]
2025-06-28 EdgeCut エラーの修正
    [2U-NTP-Clock.kicad_pcb]
